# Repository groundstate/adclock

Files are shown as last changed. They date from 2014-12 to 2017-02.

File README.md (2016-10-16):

Installation
------------

Setting up a BeagleBone Black
-----------------------------

Configuration file
------------------

`adclock` uses a configuration file `adclock.xml`. The comments in the sample file should be enough to get you going.
The search path for this is `./:~/adclock:~/.adclock:/usr/local/etc:/etc`
All other paths are explicit.

Known bugs/quirks
-----------------

Website
-------

There's a bit more information and screenshots at [ninepointtwoghz.org](http://ninepointtwoghz.org/analog-digital-clock.php)

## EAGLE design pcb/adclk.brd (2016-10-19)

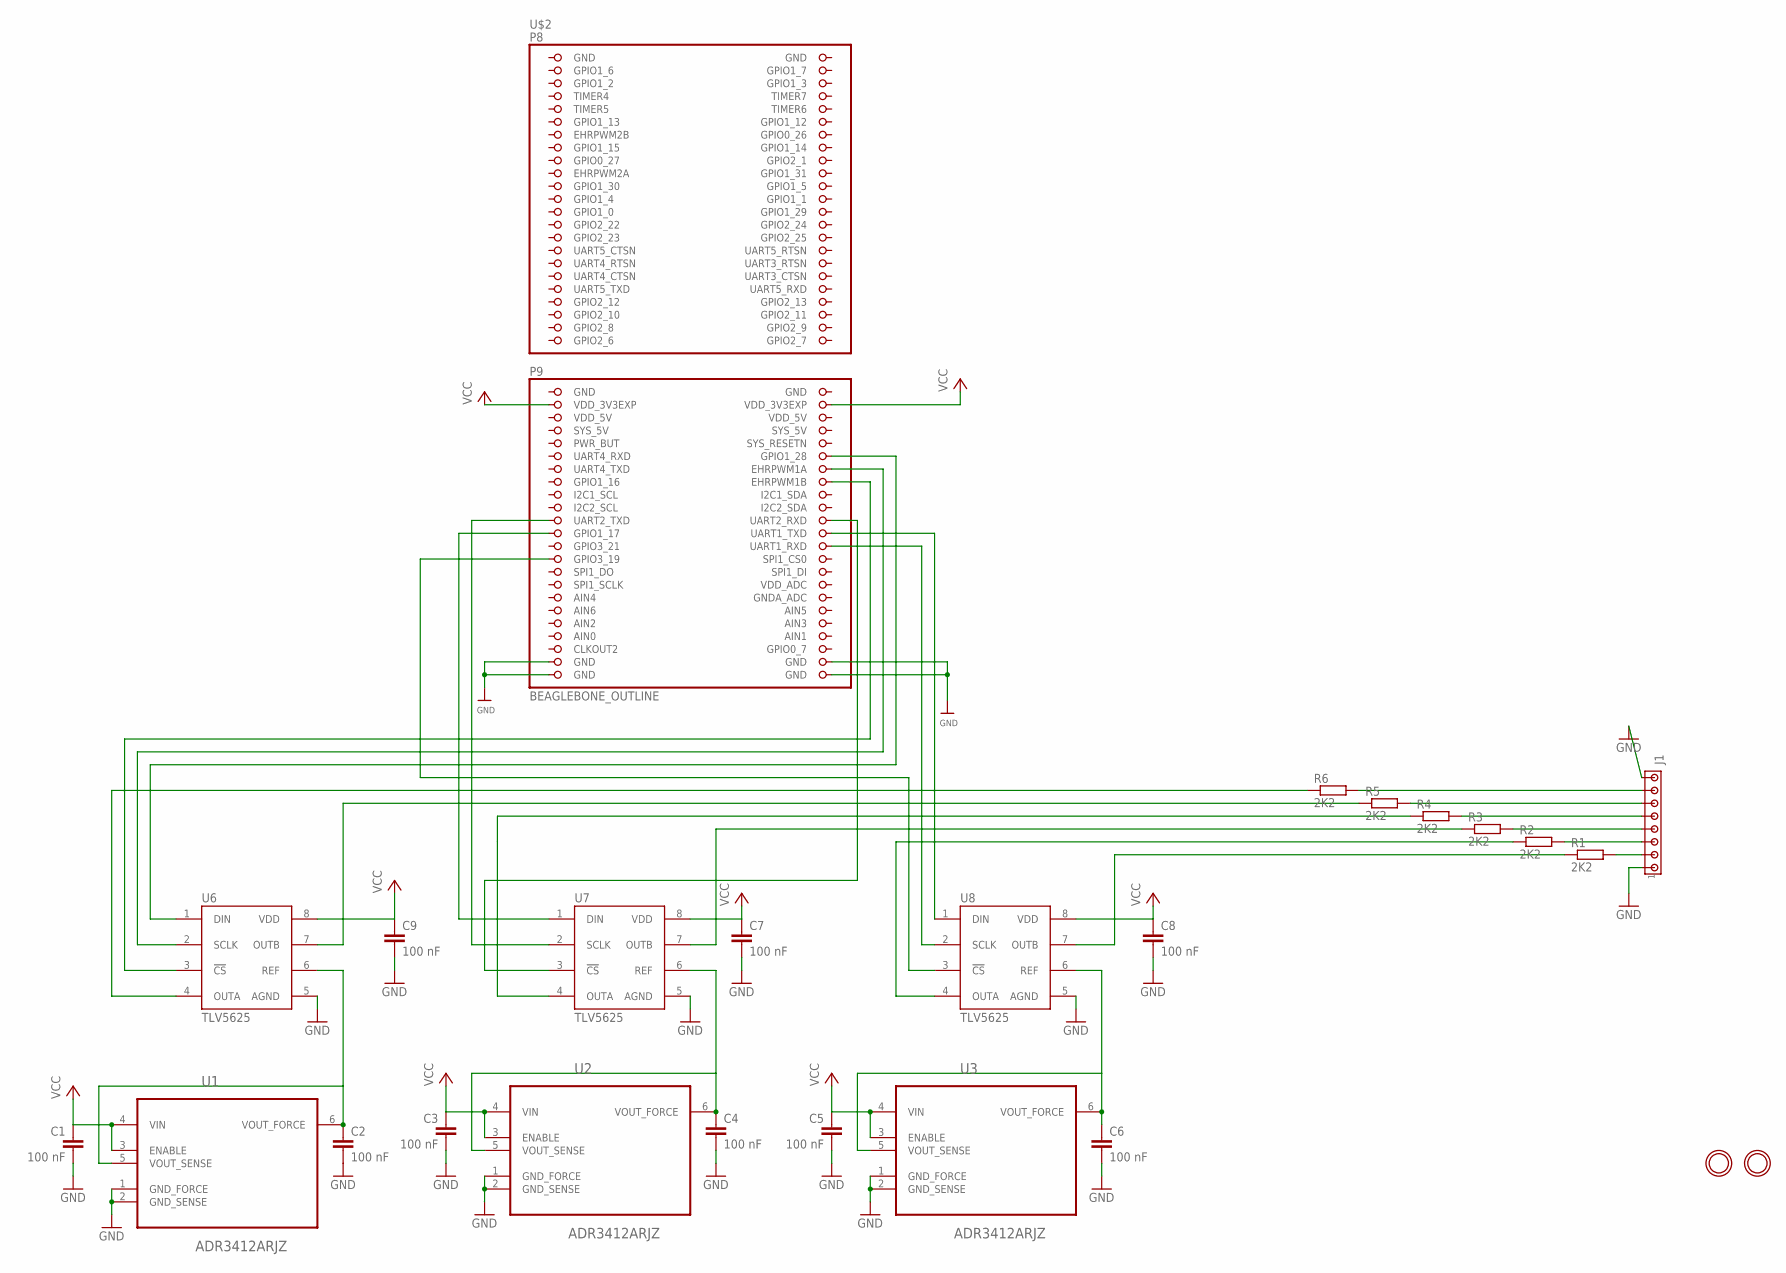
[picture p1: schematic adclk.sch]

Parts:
C1, C2, C3, C4, C5, C6, C7, C8, C9: 100 nF; C1808
J1: MTA08-100; 10X08MTA
R1, R2, R3, R4, R5, R6: 2K2; R0805
U1, U2, U3: ADR3412ARJZ; SOT95P280X145-6N
U6, U7, U8: TLV5625; SO8
U$2: BEAGLEBONE_OUTLINE; BEAGLEBONE_SHIELD
U$22, U$23: MOUNTINGHOLE3.0THIN; MOUNTINGHOLE_3.0_PLATEDTHIN

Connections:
AIN0: U$2.85 (AIN0)
AIN3: U$2.84 (AIN3)
GND: C1.2, C2.2, C3.2, C4.2, C5.2, C6.2, C7.2, C8.2, C9.2, J1.1, J1.8, U1.1 (GND_FORCE), U1.2 (GND_SENSE), U2.1 (GND_FORCE), U2.2 (GND_SENSE), U3.1 (GND_FORCE), U3.2 (GND_SENSE), U6.5 (AGND), U7.5 (AGND), U8.5 (AGND), U$2.1 (GND), U$2.2 (GND), U$2.47 (GND), U$2.48 (GND), U$2.89 (GND), U$2.90 (GND), U$2.91 (GND), U$2.92 (GND)
GPIO1_6: U$2.3 (GPIO1_6)
GPIO1_7: U$2.4 (GPIO1_7)
GPIO2_6: U$2.45 (GPIO2_6)
GPIO2_7: U$2.46 (GPIO2_7)
GPIO2_8: U$2.43 (GPIO2_8)
GPIO2_9: U$2.44 (GPIO2_9)
GPIO2_11: U$2.42 (GPIO2_11)
unnamed: J1.7, R6.2
unnamed: J1.6, R5.2
unnamed: J1.5, R4.2
unnamed: J1.4, R3.2
unnamed: J1.3, R2.2
unnamed: J1.2, R1.2
unnamed: C2.1, U1.5 (VOUT_SENSE), U1.6 (VOUT_FORCE), U6.6 (REF)
unnamed: R1.1, U8.7 (OUTB)
unnamed: C4.1, U2.5 (VOUT_SENSE), U2.6 (VOUT_FORCE), U7.6 (REF)
unnamed: R2.1, U8.4 (OUTA)
unnamed: C6.1, U3.5 (VOUT_SENSE), U3.6 (VOUT_FORCE), U8.6 (REF)
unnamed: R3.1, U7.7 (OUTB)
unnamed: R4.1, U7.4 (OUTA)
unnamed: R5.1, U6.7 (OUTB)
unnamed: R6.1, U6.4 (OUTA)
unnamed: U6.1 (DIN), U$2.58 (GPIO1_28)
unnamed: U6.2 (SCLK), U$2.60 (EHRPWM1A)
unnamed: U6.3 (!CS!), U$2.62 (EHRPWM1B)
unnamed: U8.1 (DIN), U$2.70 (UART1_TXD)
unnamed: U8.2 (SCLK), U$2.72 (UART1_RXD)
unnamed: U8.3 (!CS!), U$2.73 (GPIO3_19)
unnamed: U7.1 (DIN), U$2.69 (GPIO1_17)
unnamed: U7.3 (!CS!), U$2.68 (UART2_RXD)
unnamed: U7.2 (SCLK), U$2.67 (UART2_TXD)
VCC: C1.1, C3.1, C5.1, C7.1, C8.1, C9.1, U1.3 (ENABLE), U1.4 (VIN), U2.3 (ENABLE), U2.4 (VIN), U3.3 (ENABLE), U3.4 (VIN), U6.8 (VDD), U7.8 (VDD), U8.8 (VDD), U$2.49 (VDD_3V3EXP), U$2.50 (VDD_3V3EXP)
VDD_5V: U$2.51 (VDD_5V), U$2.52 (VDD_5V)

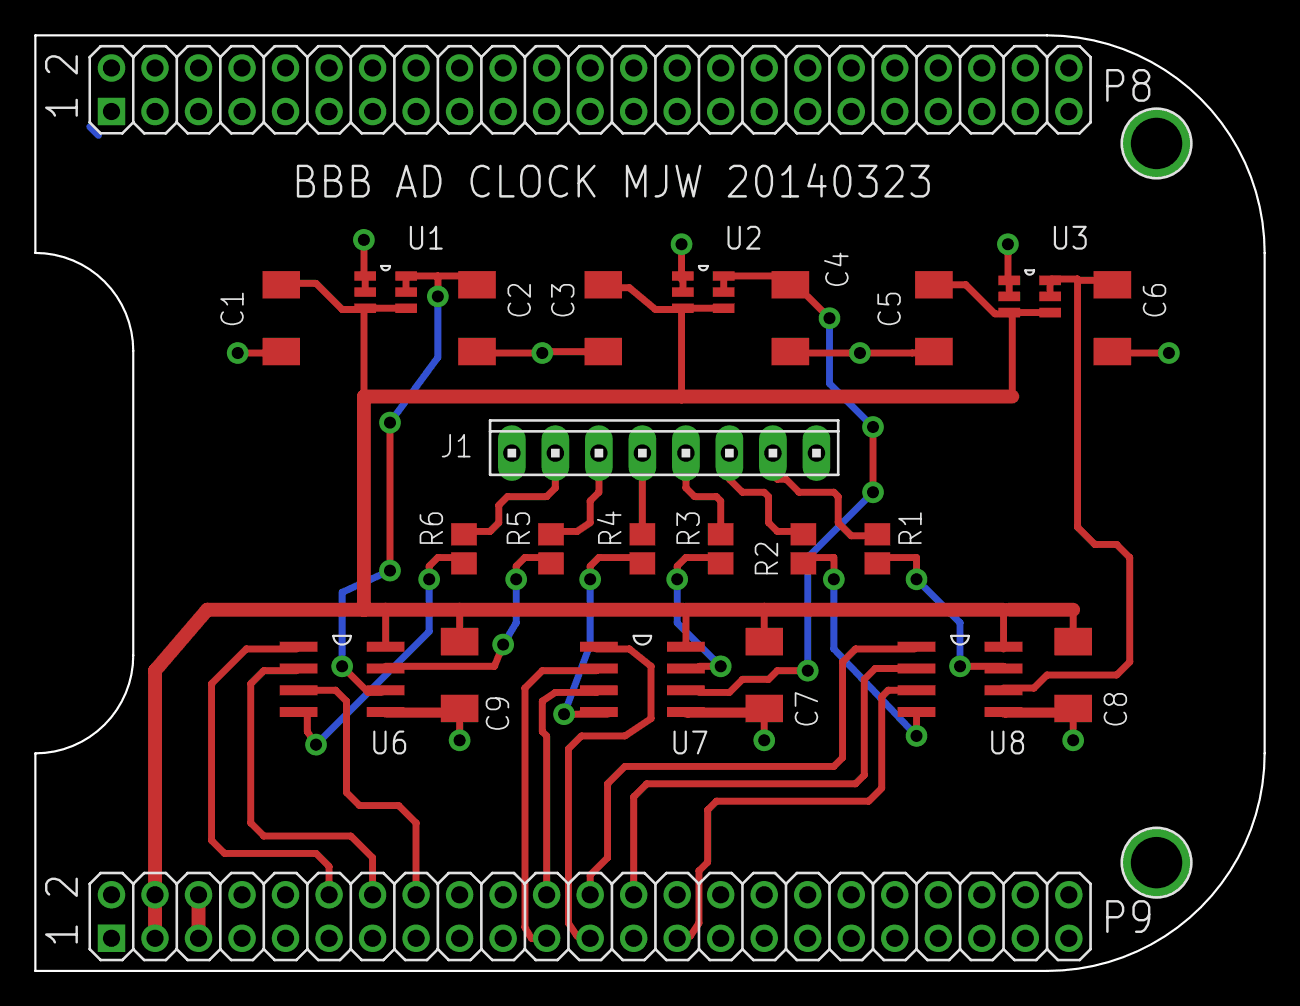
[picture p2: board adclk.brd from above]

Board: 2 copper layers, 71.8 x 54.6 mm, 25 parts (0 on the bottom side), 27 nets.

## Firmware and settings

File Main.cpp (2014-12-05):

//
// adclock -  a program for driving an analog time display on the Beaglebone
//
// The MIT License (MIT)
//
// Copyright (c) 2014  Michael J. Wouters
// 
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
#include <cstdlib>

#include "ADClock.h"

ADClock *app;
ostream * debugStream;

int main(int argc,char **argv)
{
	app  = new ADClock(argc,argv);
	app->run();
}

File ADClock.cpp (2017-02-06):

//
// adclock - a program for driving an analog time display on the Beaglebone
//
// The MIT License (MIT)
//
// Copyright (c) 2014  Michael J. Wouters
// 
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
#include <signal.h>
#include <sys/types.h>
#include <sys/stat.h>
#include <sys/time.h>
#include <unistd.h>
#include <errno.h>
#include <limits.h>

#include <cmath>
#include <cstdlib>
#include <iostream>

#include "ADClock.h"
#include "Debug.h"
#include "Version.h"
#include "tinyxml.h"
#include "TLV5625.h"

#define APP_NAME "adclock"
#define APP_VERSION "0.1"
#define APP_AUTHOR "Michael Wouters"
#define PRETTIFIER "*******************************************************"

extern ADClock* app;
extern ostream *debugStream;

ADClock::ADClock(int argc,char **argv)
{
	debugStream= NULL;
	testMode=NO_TEST;
	logFileName = string(APP_NAME) + ".log";
	int c;
	
	while ((c=getopt(argc,argv,"d:fhlrvz")) != -1){
		switch(c){
			case 'h':showHelp(); exit(EXIT_SUCCESS);
			case 'v':showVersion();exit(EXIT_SUCCESS);
			case 'd':
			{
				string dbgout = optarg;
				if ((string::npos != dbgout.find("stderr"))){
					debugStream = & std::cerr;
				}
				else{
					debugFileName = dbgout;
					debugLog.open(debugFileName.c_str(),ios_base::app);
					if (!debugLog.is_open()){
						cerr << "Unable to open " << dbgout << endl;
						exit(EXIT_FAILURE);
					}
					debugStream = & debugLog;
				}
				break;
			}
			case 'f':
			{
				testMode = FSD_DACS;
				break;
			}
			case 'l':
			{
				showLicense();
				exit(EXIT_SUCCESS);
			}
			case 'r':
			{
				testMode= RAMP_DACS;
				break;
			}
			case 'z':
			{
				testMode= ZERO_DACS;
				break;
			}
			default:
				break;
		}
	}
	
  init( argc, argv );
	
	timezone=":"+timezone; // set from file
	setenv("TZ",timezone.c_str(),1);
	tzset();
	
	secsDAC=new TLV5625(15,14,115);
	minsDAC=new TLV5625(49,3,2);
	//hrsDAC=new TLV5625(60,50,51); // this is for the PCB as designed
	hrsDAC=new TLV5625(30,50,51);   // and this is a hack for my dead GPIO
	
	
}

ADClock::~ADClock()
{
	log("exiting");
	appLog.close();
	debugLog.close();
	hrsDAC->writeDACs(0,0);
	minsDAC->writeDACs(0,0);
	secsDAC->writeDACs(0,0);
	delete hrsDAC;
	delete minsDAC;
	delete secsDAC;
	exit(EXIT_SUCCESS);
}

void ADClock::run()
{
	switch (testMode)
	{
		case ZERO_DACS:
			hrsDAC->writeDACs(0,0);
			minsDAC->writeDACs(0,0);
			secsDAC->writeDACs(0,0);
			waitForKeyPress();
			delete this;
			break;
		case FSD_DACS:
			hrsDAC->writeDACs(2*hrsTensCal,9*hrsUnitsCal);
			minsDAC->writeDACs(5*minsTensCal,9*minsUnitsCal);
			secsDAC->writeDACs(5*secsTensCal,9*secsUnitsCal);
			waitForKeyPress();
			delete this;
			break;
		case RAMP_DACS:
			runDACtest("Seconds - units",secsDAC,2);
			runDACtest("Seconds - tens",secsDAC,1);
			runDACtest("Minutes - units",minsDAC,2);
			runDACtest("Minutes - tens",minsDAC,1);
			runDACtest("Hours - units",hrsDAC,2);
			runDACtest("Hours - tens",hrsDAC,1);
			delete this;
			break;
		default:
			break;
	}
	
	 while (1){
		struct timeval tv;
		gettimeofday(&tv,NULL);
		usleep(1000000-tv.tv_usec);
		gettimeofday(&tv,NULL);
		struct tm *ltm = localtime(&tv.tv_sec);
		DBGMSG(debugStream,tv.tv_usec << ": " << ltm->tm_min << " " << ltm->tm_sec);
		//
		unsigned short int tens=ltm->tm_sec/10;
		unsigned short int units=ltm->tm_sec-10*tens;
		tens=tens*secsTensCal;
		units=units*secsUnitsCal;
		secsDAC->writeDACs(tens,units);
		
		tens=ltm->tm_min/10;
		units=ltm->tm_min-10*tens;
		tens=tens*minsTensCal;
		units=units*minsUnitsCal;
		minsDAC->writeDACs(tens,units);
		
		tens=ltm->tm_hour/10;
		units=ltm->tm_hour-10*tens;
		tens=tens*hrsTensCal;
		units=units*hrsUnitsCal;
		hrsDAC->writeDACs(tens,units);
		
		
	}
}

void ADClock::log(string msg)
{
	//appLog <<timestamp() << " " << msg << endl;
	//appLog.flush();
	DBGMSG(debugStream,"LOG:" << msg);
}

	
//
// Private members
//

void ADClock::init(int,char **)
{
	// Set defaults
	timezone = "UTC";
	
	/* Cal factor is (DAC value for max deflection) / (max digit on meter) */
	hrsUnitsCal=235.0/10.0;
	hrsTensCal=242.0/5.0;
	
	minsUnitsCal=235.0/10.0;
	minsTensCal=240.0/5.0;
	
	secsUnitsCal=235.0/10.0;
	secsTensCal=240.0/5.0;
	
	appLog.open(logFileName.c_str(),ios_base::app);
	if (!appLog.is_open()){
		cerr << "Unable to open " << logFileName << endl;
	}
	log(PRETTIFIER);
	log(string(APP_NAME) +  string(" v") + 
		string(APP_VERSION) + string(", last modified ") + string(LAST_MODIFIED));
	log(PRETTIFIER);
	
	string cfgPath=getConfigPath();
	if (cfgPath.size() > 0)
		readConfig(cfgPath);
	else
		cerr << "A configuration file could not be found" << endl;
	
	struct sigaction sa;
	sigset_t sigioset;
	
	sa.sa_handler = signalHandler;
	
	sigemptyset(&(sa.sa_mask)); // we block nothing 
	sa.sa_flags=0;    
	
	sigaddset(&sigioset,SIGTERM);
	if (sigaction(SIGTERM,&sa,NULL)==-1)
		perror("Wot?");
	
	sigaddset(&sigioset,SIGQUIT);
	sigaction(SIGQUIT,&sa,NULL);
	
	sigaddset(&sigioset,SIGINT);
	if (sigaction(SIGINT,&sa,NULL)==-1)
		perror("WotWot?");
	
	sigaddset(&sigioset,SIGHUP);
	sigaction(SIGHUP,&sa,NULL);
	
}

string ADClock::getConfigPath()
{

	struct stat statbuf;
	 
	std::string cfgPath("./adclock.xml");// working directory first
	if ((0 == stat(cfgPath.c_str(),&statbuf)))
		return cfgPath;
	
	char *homedir = getenv("HOME");
	if (homedir){ // may be running as a system service without HOME
	cfgPath= string(homedir) +string("/adclock/adclock.xml");
		if ((0 == stat(cfgPath.c_str(),&statbuf)))
			return cfgPath;

		cfgPath= string(homedir) + string("/.adclock/adclock.xml");
		if ((0 == stat(cfgPath.c_str(),&statbuf)))
			return cfgPath;
	}
	
	cfgPath= "/usr/local/share/adclock/adclock.xml";
	if ((0 == stat(cfgPath.c_str(),&statbuf)))
		return cfgPath;
	
	cfgPath= "/usr/share/adclock/adclock.xml";
	if ((0 == stat(cfgPath.c_str(),&statbuf)))
		return cfgPath;
	
	cfgPath="";
	
	return cfgPath;
}

bool ADClock::readConfig(string configPath)
{
	TiXmlDocument doc( configPath.c_str() );
  if (!doc.LoadFile()){
		cerr << "Error loading document: " << doc.ErrorDesc() << endl;
		cerr << "The configuration file " << configPath << " could not be opened" << endl;
		return false;
	}
	
	log(string("using config file ") + configPath);
		
  TiXmlElement* root = doc.RootElement( );

  if (0 != strcmp(root->Value(), "adclock") ) {
		return false;
  }
	
	for ( TiXmlElement* elem = root->FirstChildElement();elem;elem = elem->NextSiblingElement() ){
		if (0 == strcmp(elem->Value(),"timezone")){
			const char *text = elem->GetText();
			if (text)
				timezone = text;
		}
		else if (0 == strcmp(elem->Value(),"hours")){
			readDACconfig(elem,&hrsUnitsCal,&hrsTensCal);
		}
		else if (0 == strcmp(elem->Value(),"minutes")){
			readDACconfig(elem,&minsUnitsCal,&minsTensCal);
		}
		else if (0 == strcmp(elem->Value(),"seconds")){
			readDACconfig(elem,&secsUnitsCal,&secsTensCal);
		}
	}
	
	return true;
}
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

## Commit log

2016-10-16 Added overlay. Note that an extra pin is used because of a dead pin on my BB.
2016-10-19 Added Eagle PCB files (since they are now verified to work!)
    [adclk.brd, adclk.sch]
2017-02-05 Minor oopsies. Config file was broken. Ramp test had units/tens swapped.
    [ADClock.cpp]
2017-02-06 Better install. startup as systemd service. Bug fix - HOME not defined when running as a system service.
    [ADClock.cpp]
